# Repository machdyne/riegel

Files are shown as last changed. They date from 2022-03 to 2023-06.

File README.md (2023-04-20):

# Riegel Computer

Riegel is an FPGA computer designed by Lone Dynamics Corporation.

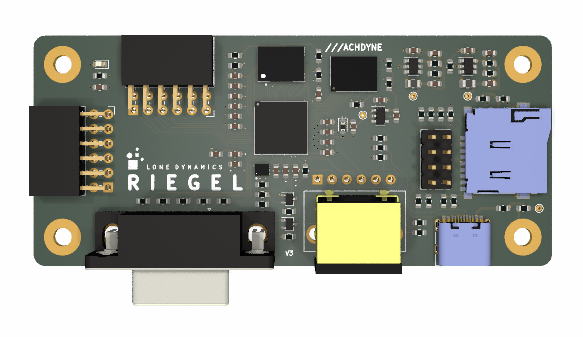
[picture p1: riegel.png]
Riegel Computer


This repo contains schematics, PCB layouts, pinouts, a 3D-printable case, example gateware and documentation.

Find more information on the [Riegel product page](https://machdyne.com/product/riegel-computer/).

## Blinky 

Building the blinky example requires [Yosys](https://github.com/YosysHQ/yosys), [nextpnr-ice40](https://github.com/YosysHQ/nextpnr) and [IceStorm](https://github.com/YosysHQ/icestorm).

Assuming they are installed, you can simply type `make` to build the gateware, which will be written to output/blinky.bin. You can then use [ldprog](https://github.com/machdyne/ldprog) to write the gateware to the device.

## Zucker

[Zucker](https://github.com/machdyne/zucker) is a RISC-V SOC designed specifically for Riegel hardware.

## USB Bootloader

Riegel supports updating the flash MMOD over its USB-C port with the USB DFU (Device Firmware Upgrade) protocol. When Riegel powers on (or restarts) the USB bootloader waits 5 seconds for a USB command and then continues the boot process, if it receives a command it will wait until the device is detached (with `dfu-util -e`) or rebooted (with `ldprog -r`).

In order to install the USB bootloader you will need to use the ISP header and [ldprog](https://github.com/machdyne/ldprog). Make sure you have first installed the software required to build the Blinky example above.

```
git clone https://github.com/machdyne/tinydfu-bootloader
cd tinydfu-bootloader/boards/riegel
make
make prog
```

Now you can program the flash MMOD over USB:

```
ldprog -r
sudo dfu-util -a 0 -D zucker/output/soc.bin
sudo dfu-util -a 1 -D zucker/apps/lix/lix.bin
```

Note: It may be necessary to remove the MicroSD card before programming with DFU.

Exit the bootloader and continue booting:

```
sudo dfu-util -e -a 0
```

## ISP Header

The ISP header can be used to program the FPGA SRAM as well as the MMOD flash memory. 

```
1 2
3 4
5 6
7 8
```

| Pin | Signal |
| --- | --- |
| 1 | CSPI\_SS |
| 2 | CSPI\_SCK |
| 3 | CSPI\_SI |
| 4 | CSPI\_SO |
| 5 | CRESET |
| 6 | CDONE |
| 7 | GND |
| 8 | PWR3V3 (out) |

## Board Revisions

| Revision | Notes |
| --- | ----- |
| V3B | Latest production board |
| V4 | Work in progress; improves USB routing  |

## License

The contents of this repo are released under the [Lone Dynamics Open License](LICENSE.md) with the following exceptions:

- The KiCad design files contain parts of the [kicad-pmod](https://github.com/mithro/kicad-pmod) library which is released under the [Apache License, Version 2.0](https://www.apache.org/licenses/LICENSE-2.0.html).

- The KiCad design files may contain symbols and footprints released under other licenses; please contact us if we've failed to give proper attribution.

Note: You can use these designs for commercial purposes but we ask that instead of producing exact clones, that you either replace our trademarks and logos with your own or add your own next to ours.

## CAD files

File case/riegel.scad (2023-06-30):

/*
 * Riegel Case
 * Copyright (c) 2022 Lone Dynamics Corporation. All rights reserved.
 *
 */

$fn = 100;

dev_edition = true;

board_width = 40;
board_thickness = 1.5;
board_length = 90;
board_height = 20;
board_spacing = 2;

ldq_board();

translate([0,0,15])
	ldq_case_top();

translate([0,0,-15])
	ldq_case_bottom();

module ldq_board() {
	
	difference() {
		color([0,0.5,0])
			roundedcube(board_width,board_length,board_thickness,2);
		translate([5, 5, -1]) cylinder(d=3.2, h=10);
		translate([5, 85, -1]) cylinder(d=3.2, h=10);
		translate([35, 5, -1]) cylinder(d=3.2, h=10);
		translate([35, 85, -1]) cylinder(d=3.2, h=10);
	}	
	
}

module ldq_case_top() {
	
	difference() {
				
		color([0.5,0.5,0.5])
			roundedcube(board_width,board_length,15,2);
			
		translate([1.5,2,-2])
			roundedcube(board_width-3.5,board_length-4,4,2);

		translate([1.5,10,-2])
			roundedcube(board_width-8,board_length-20,15,2);

		translate([10,2,-2])
			roundedcube(board_width-20,board_length-4,15,2);
		
		if (dev_edition) {
			// ISP header
			translate([16,66.5,2]) cube([12,6,20]);
		}
		
		// VGA
		translate([30,26.2-(31/2),-2]) cube([30,31,12.5+2]);

		// PS2
		translate([30,55.6-(14.5/2),-2]) cube([30,14.5,13+2]);

		// USBC
		translate([30,74.45-(9.5/2),-2]) cube([30,9.5,3.5+1.75]);
		
		// SD
		translate([20-(15/2),70,-2]) cube([15,30,2+2]);

		// SD resistor cutouts
		translate([8,74,-2]) cube([15,10,2+2]);
		translate([17,74,-2]) cube([15,10,2+2]);

		// PMODA
		translate([20,-2,0]) cube([16,30,10],center=true);

		// PMODB
		translate([0,23.65,0]) cube([5,16,10], center=true);
		
		// bolt holes
		translate([5, 5, -21]) cylinder(d=3.5, h=40);
		translate([5, 85, -21]) cylinder(d=3.5, h=40);
		translate([35, 5, -20]) cylinder(d=3.5, h=40);
		translate([35, 85, -21]) cylinder(d=3.5, h=40);

		// flush mount bolt holes
		translate([5, 5, 14]) cylinder(d=5, h=4);
		translate([5, 85, 14]) cylinder(d=5, h=4);
		translate([35, 5, 14]) cylinder(d=5, h=4);
		translate([35, 85, 14]) cylinder(d=5, h=4);

		// riegel text
		rotate(270)
			translate([-35,18.5,14])
				linear_extrude(5)
					text("R I E G E L", size=6, halign="center",
						font="Ubuntu:style=Bold");

	}	
}

module ldq_case_bottom() {
	
	difference() {
		color([0.5,0.5,0.5])
			roundedcube(board_width,board_length,8.5,2);
		
		translate([2,10,2])
			roundedcube(board_width-4,board_length-20,8,2);
				
		translate([10,2.5,2])
			roundedcube(board_width-20,board_length-5,8,2);

		// bolt holes
		translate([5, 5, -11]) cylinder(d=3.2, h=25);
		translate([5, 85, -11]) cylinder(d=3.2, h=25);
		translate([35, 5, -11]) cylinder(d=3.2, h=25);
		translate([35, 85, -11]) cylinder(d=3.2, h=25);

		// nut holes
		translate([5, 5, -1.5]) cylinder(d=7, h=4.5, $fn=6);
		translate([5, 85, -1.5]) cylinder(d=7, h=4.5, $fn=6);
		translate([35, 5, -1.5]) cylinder(d=7, h=4.5, $fn=6);
		translate([35, 85, -1.5]) cylinder(d=7, h=4.5, $fn=6);

	}	
}

// https://gist.github.com/tinkerology/ae257c5340a33ee2f149ff3ae97d9826
module roundedcube(xx, yy, height, radius)
{
    translate([0,0,height/2])
    hull()
    {
        translate([radius,radius,0])
        cylinder(height,radius,radius,true);

        translate([xx-radius,radius,0])
        cylinder(height,radius,radius,true);

        translate([xx-radius,yy-radius,0])
        cylinder(height,radius,radius,true);

        translate([radius,yy-radius,0])
        cylinder(height,radius,radius,true);
    }
}

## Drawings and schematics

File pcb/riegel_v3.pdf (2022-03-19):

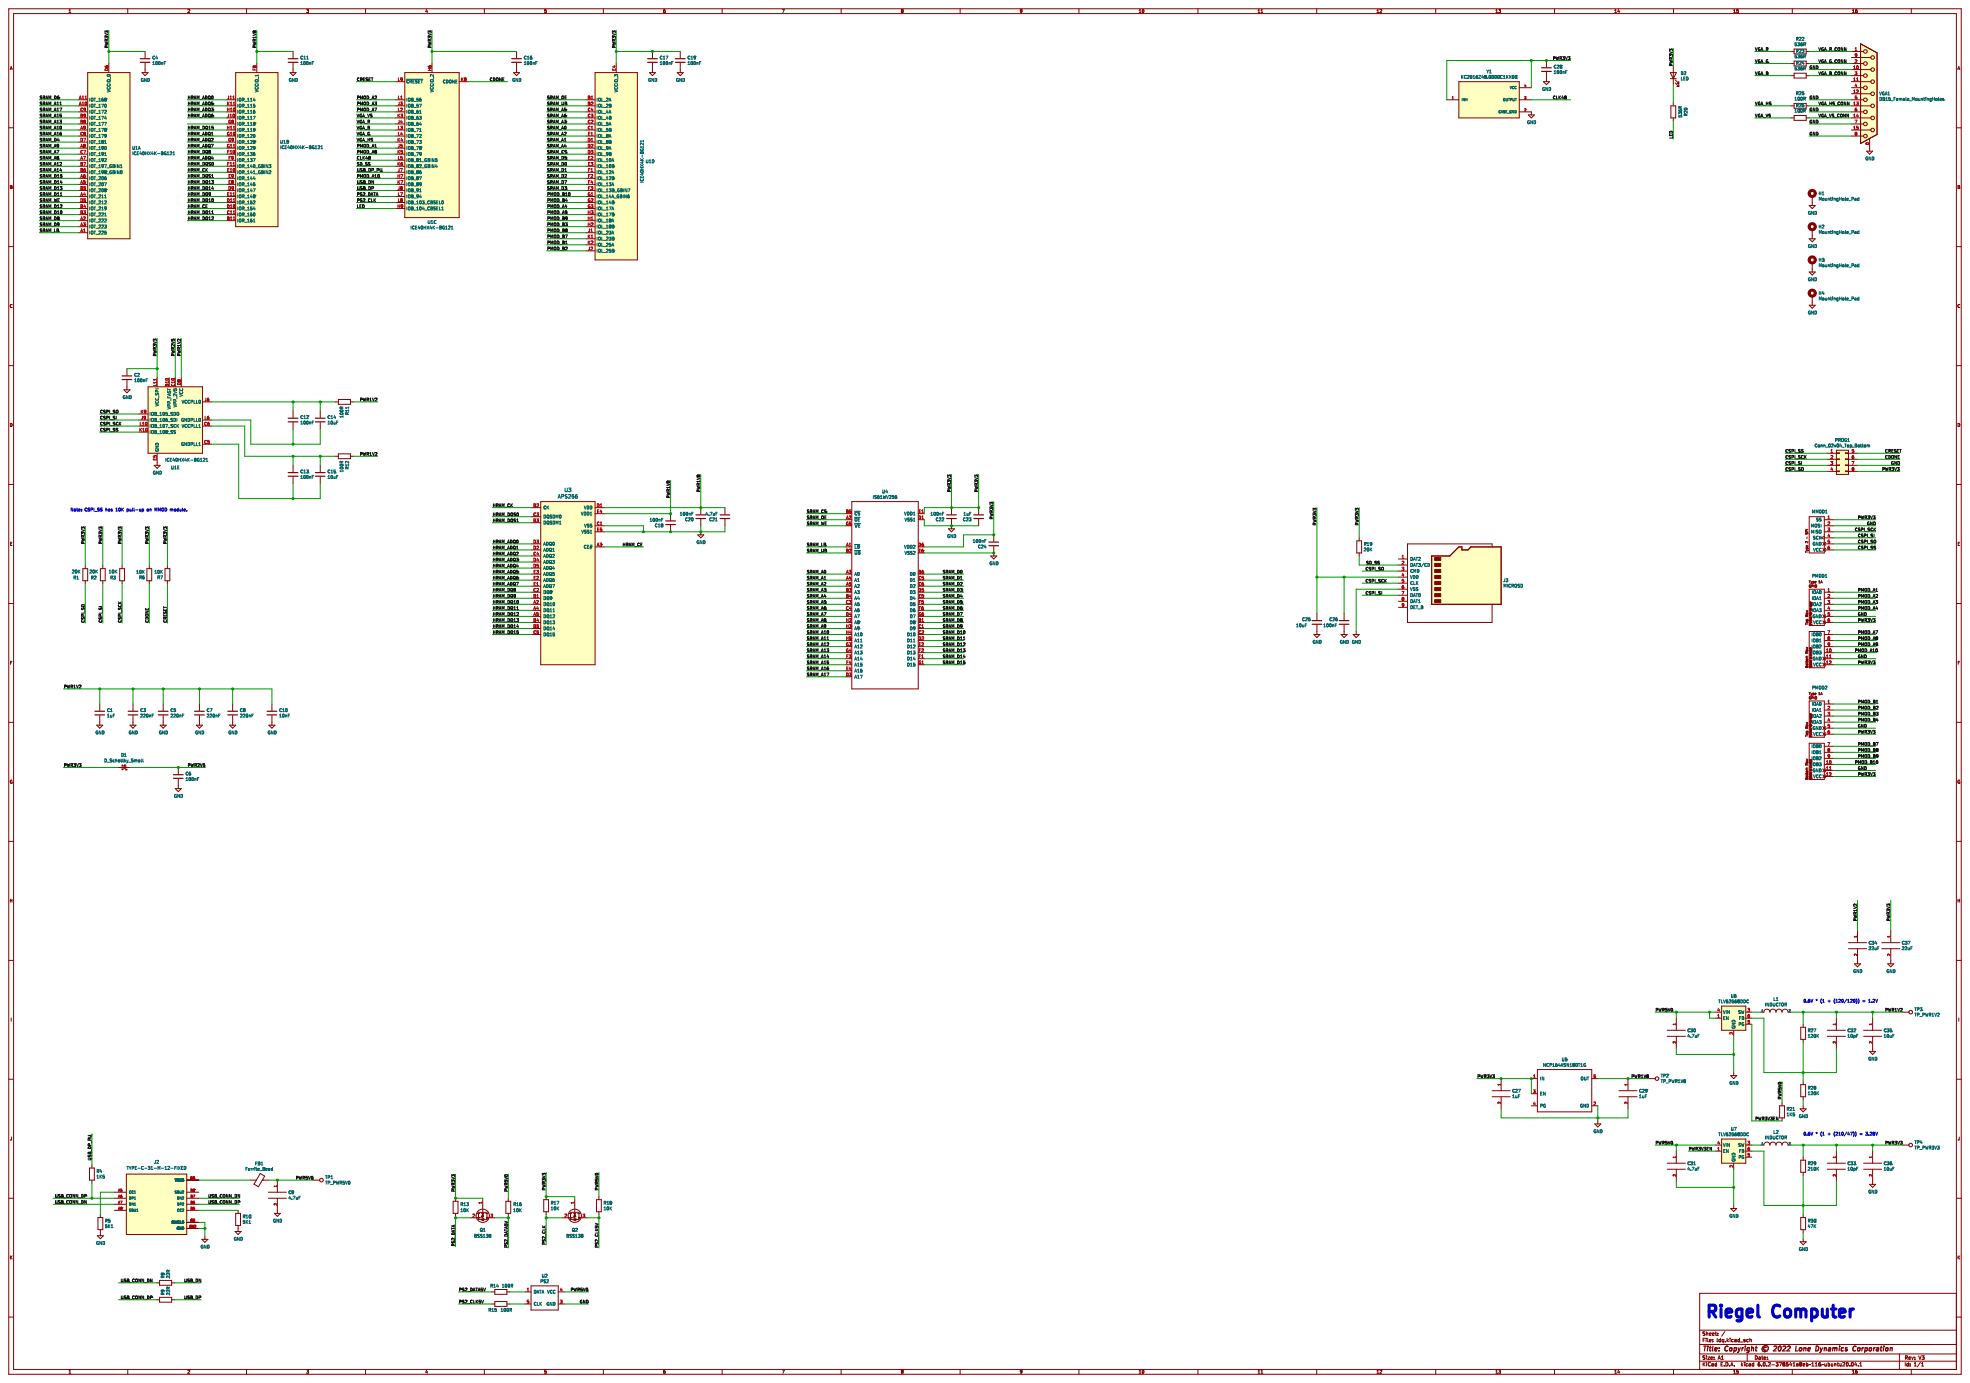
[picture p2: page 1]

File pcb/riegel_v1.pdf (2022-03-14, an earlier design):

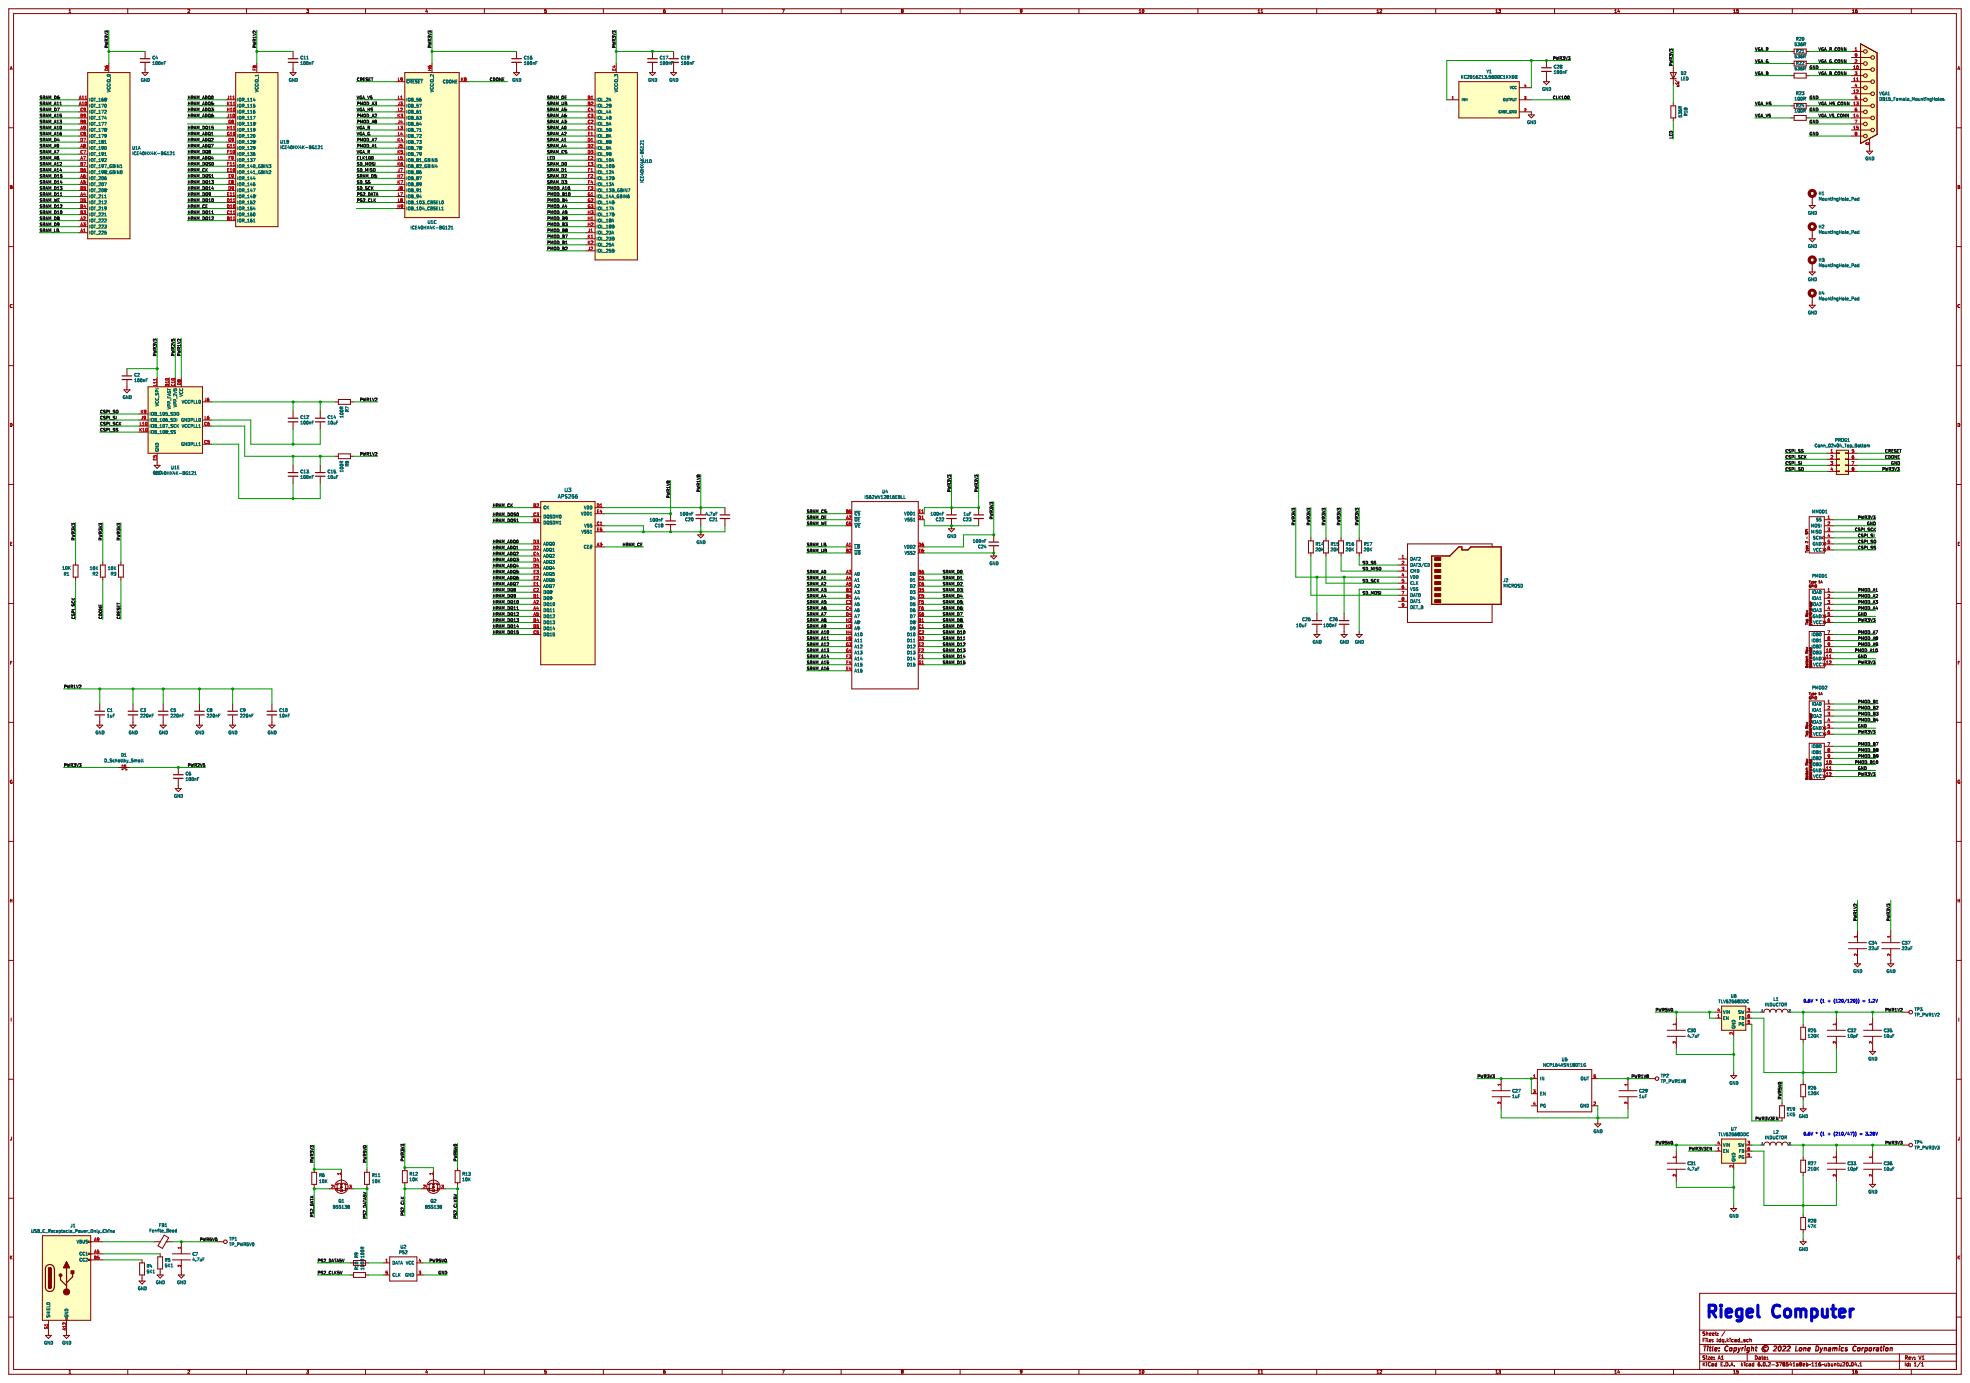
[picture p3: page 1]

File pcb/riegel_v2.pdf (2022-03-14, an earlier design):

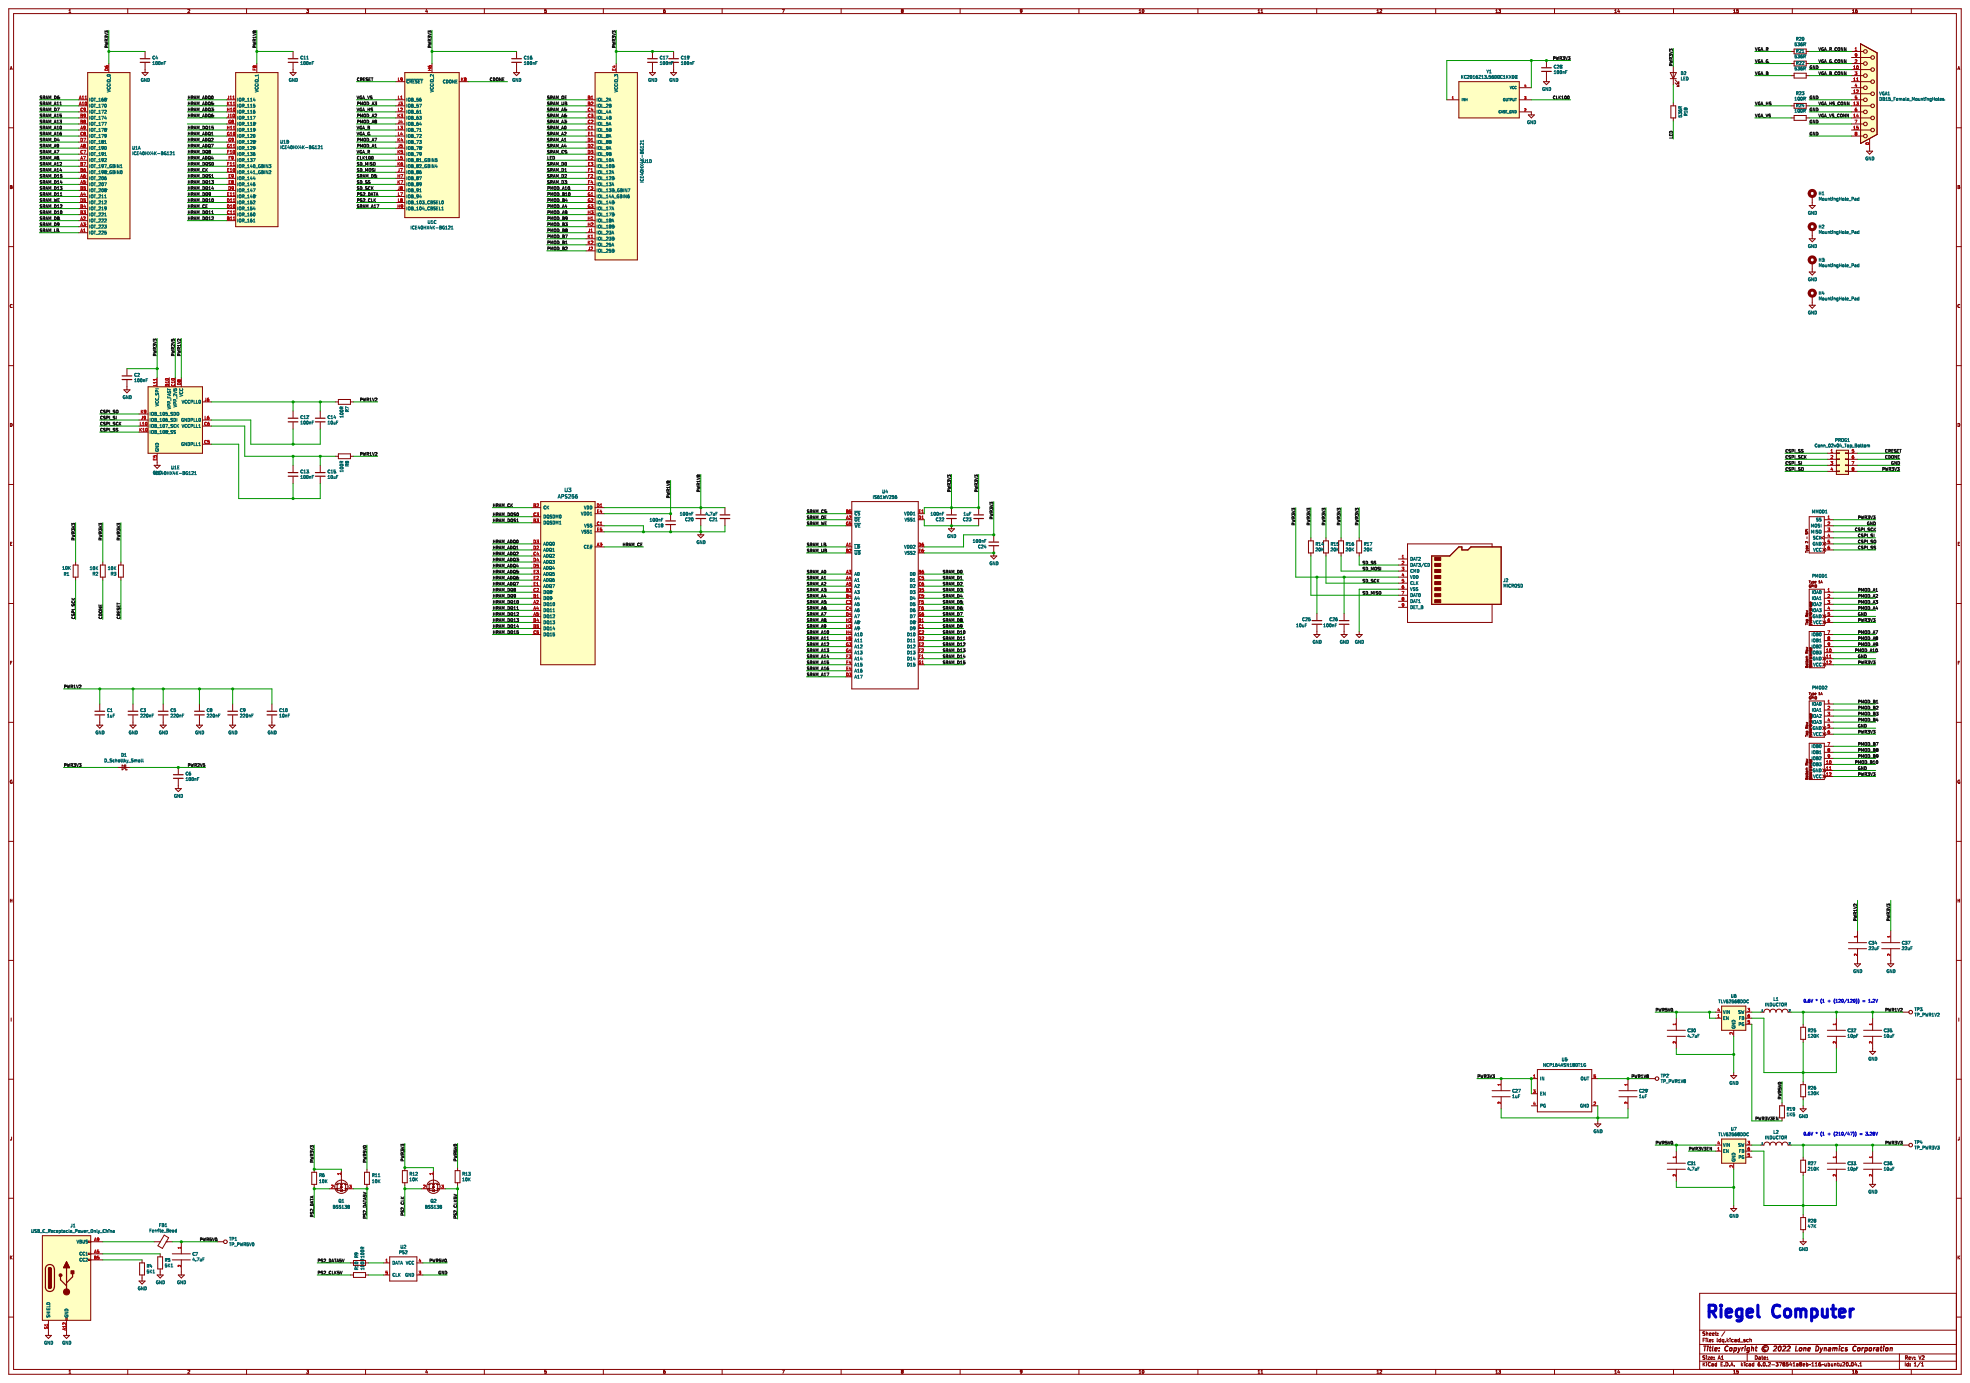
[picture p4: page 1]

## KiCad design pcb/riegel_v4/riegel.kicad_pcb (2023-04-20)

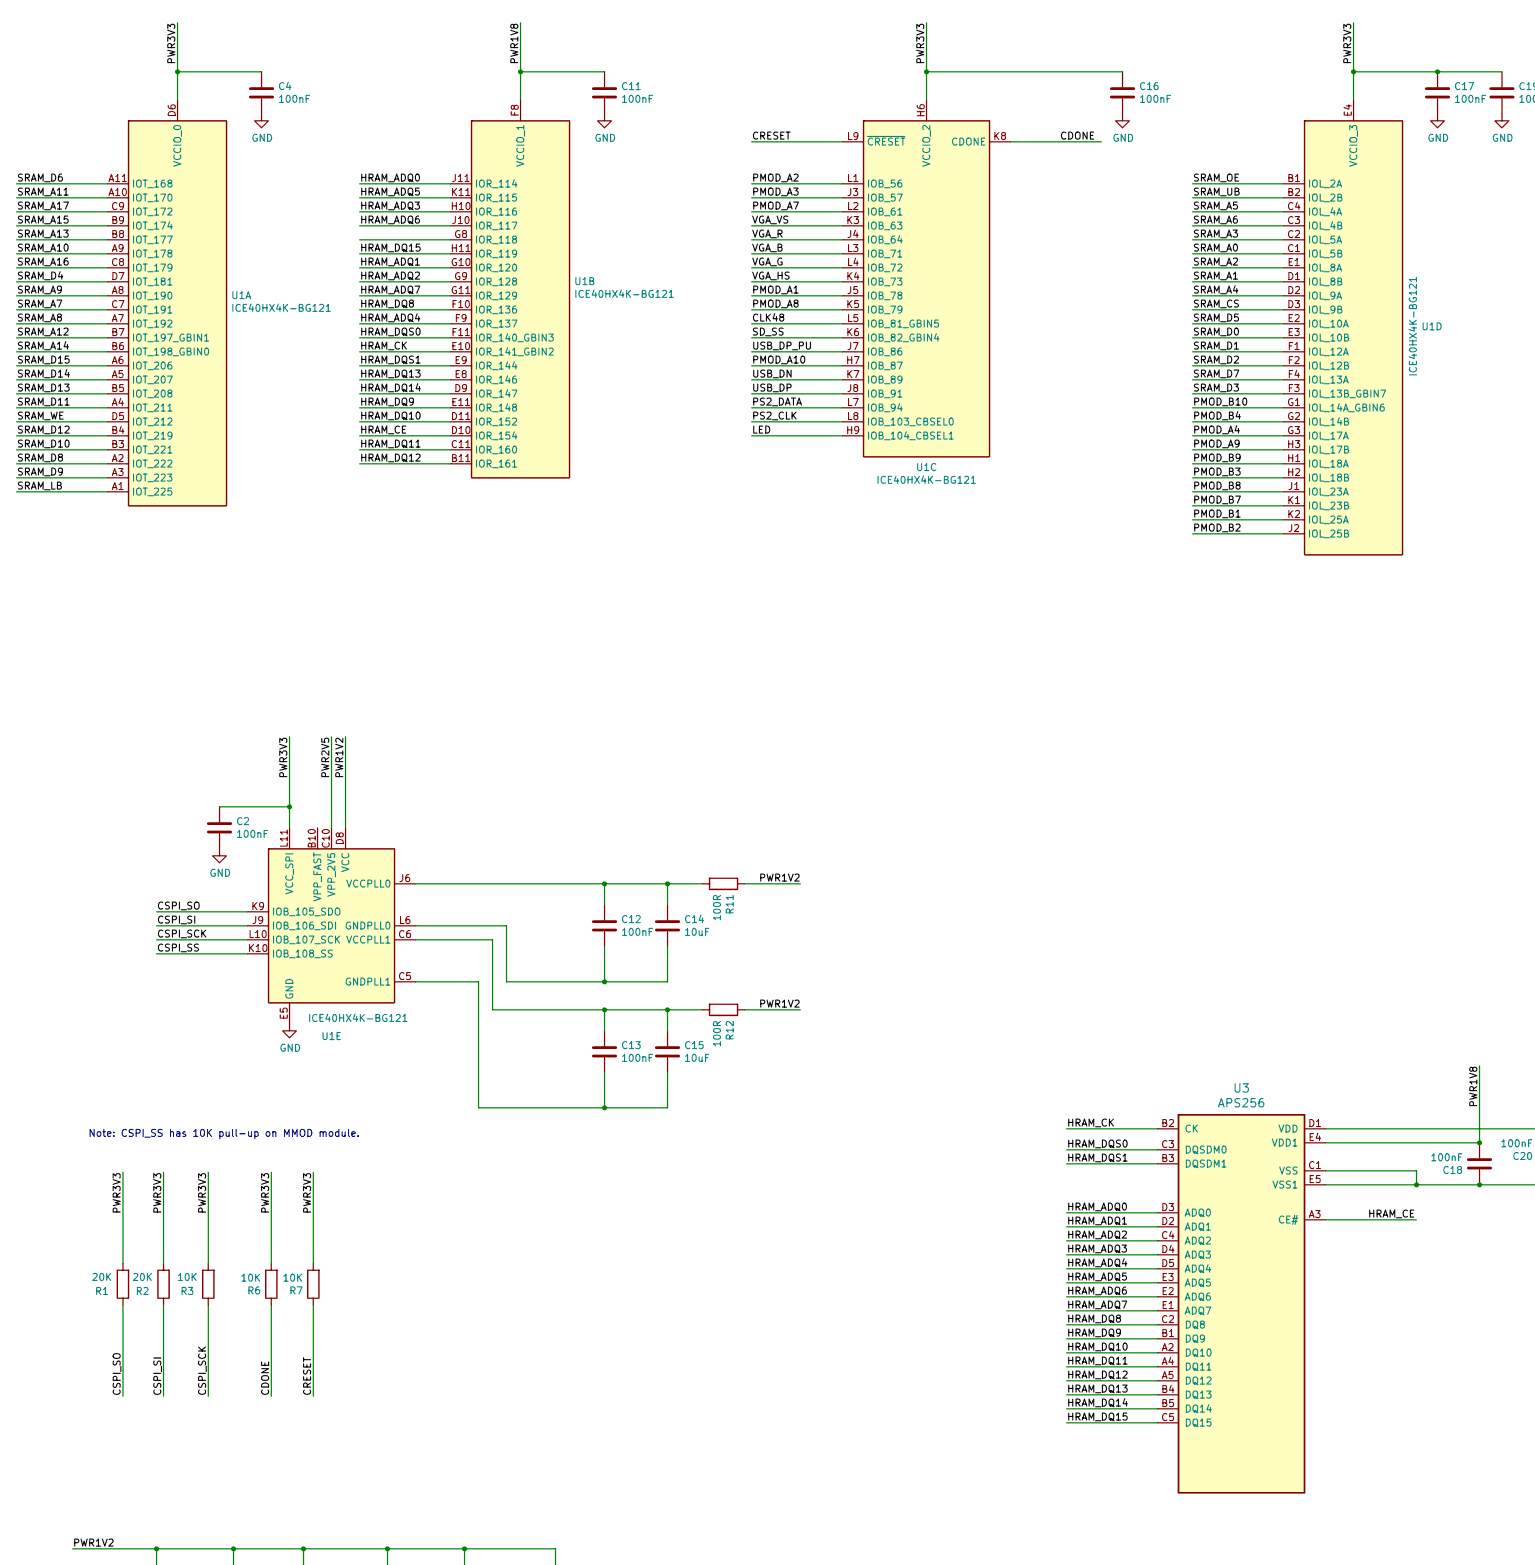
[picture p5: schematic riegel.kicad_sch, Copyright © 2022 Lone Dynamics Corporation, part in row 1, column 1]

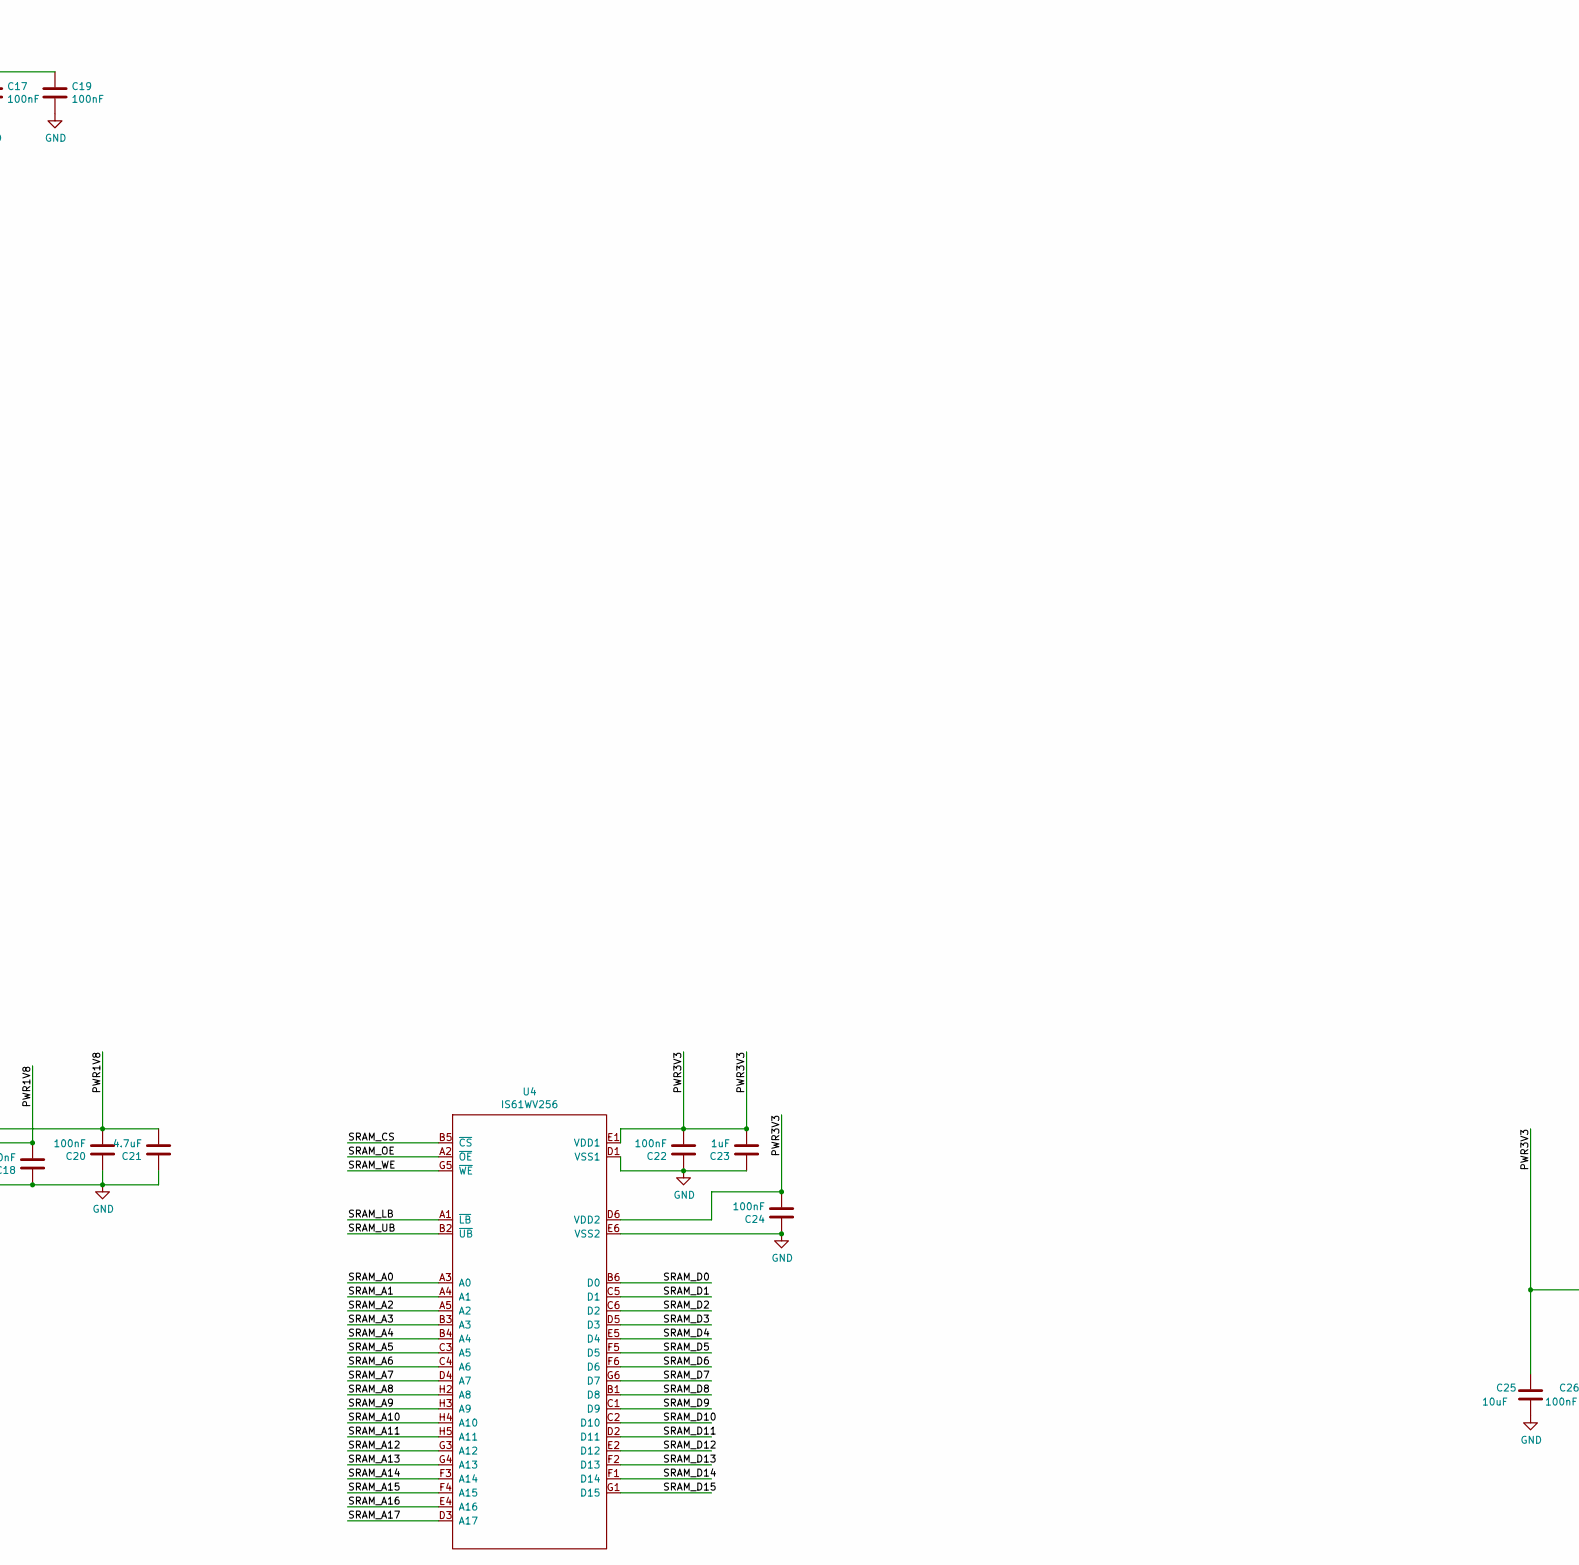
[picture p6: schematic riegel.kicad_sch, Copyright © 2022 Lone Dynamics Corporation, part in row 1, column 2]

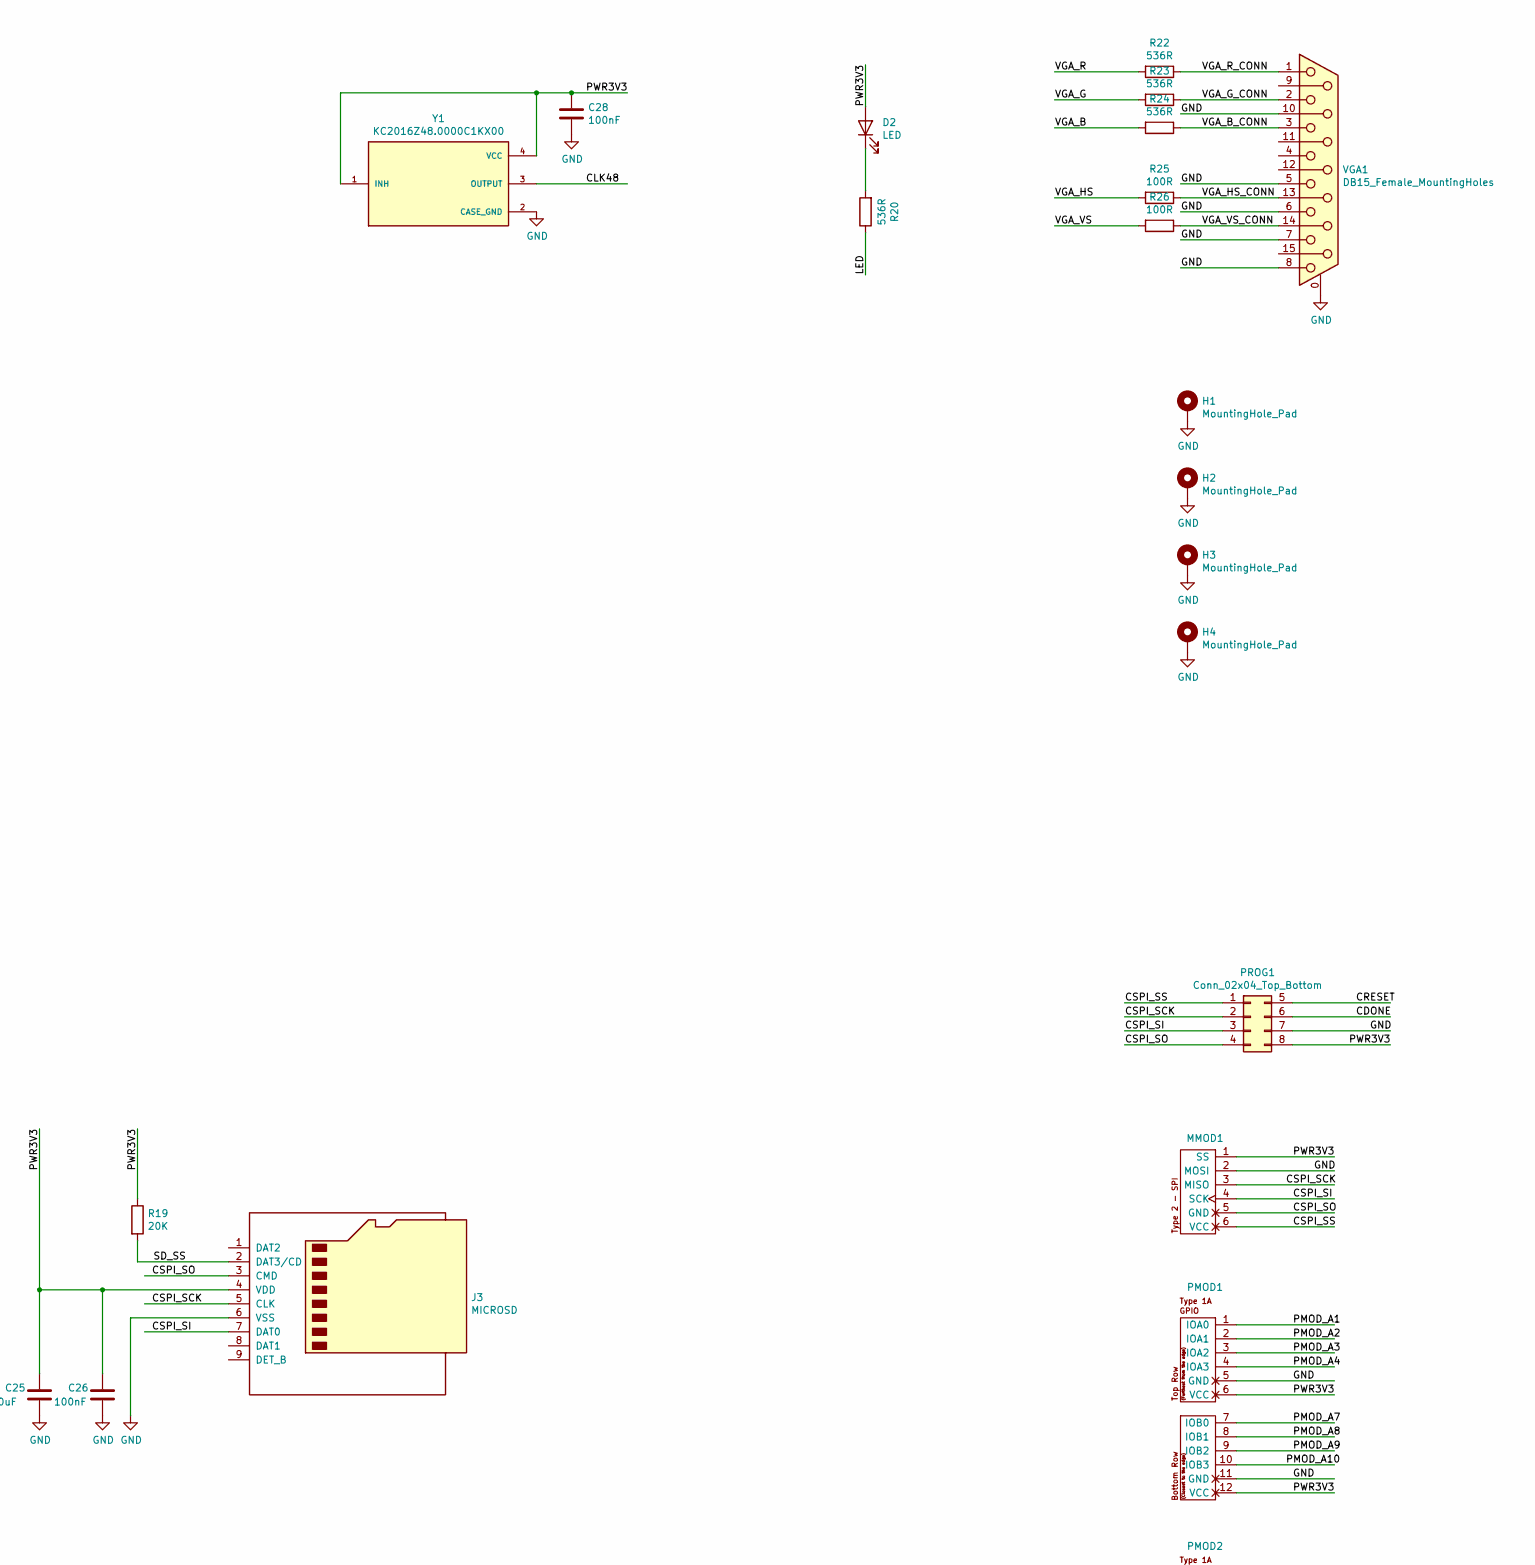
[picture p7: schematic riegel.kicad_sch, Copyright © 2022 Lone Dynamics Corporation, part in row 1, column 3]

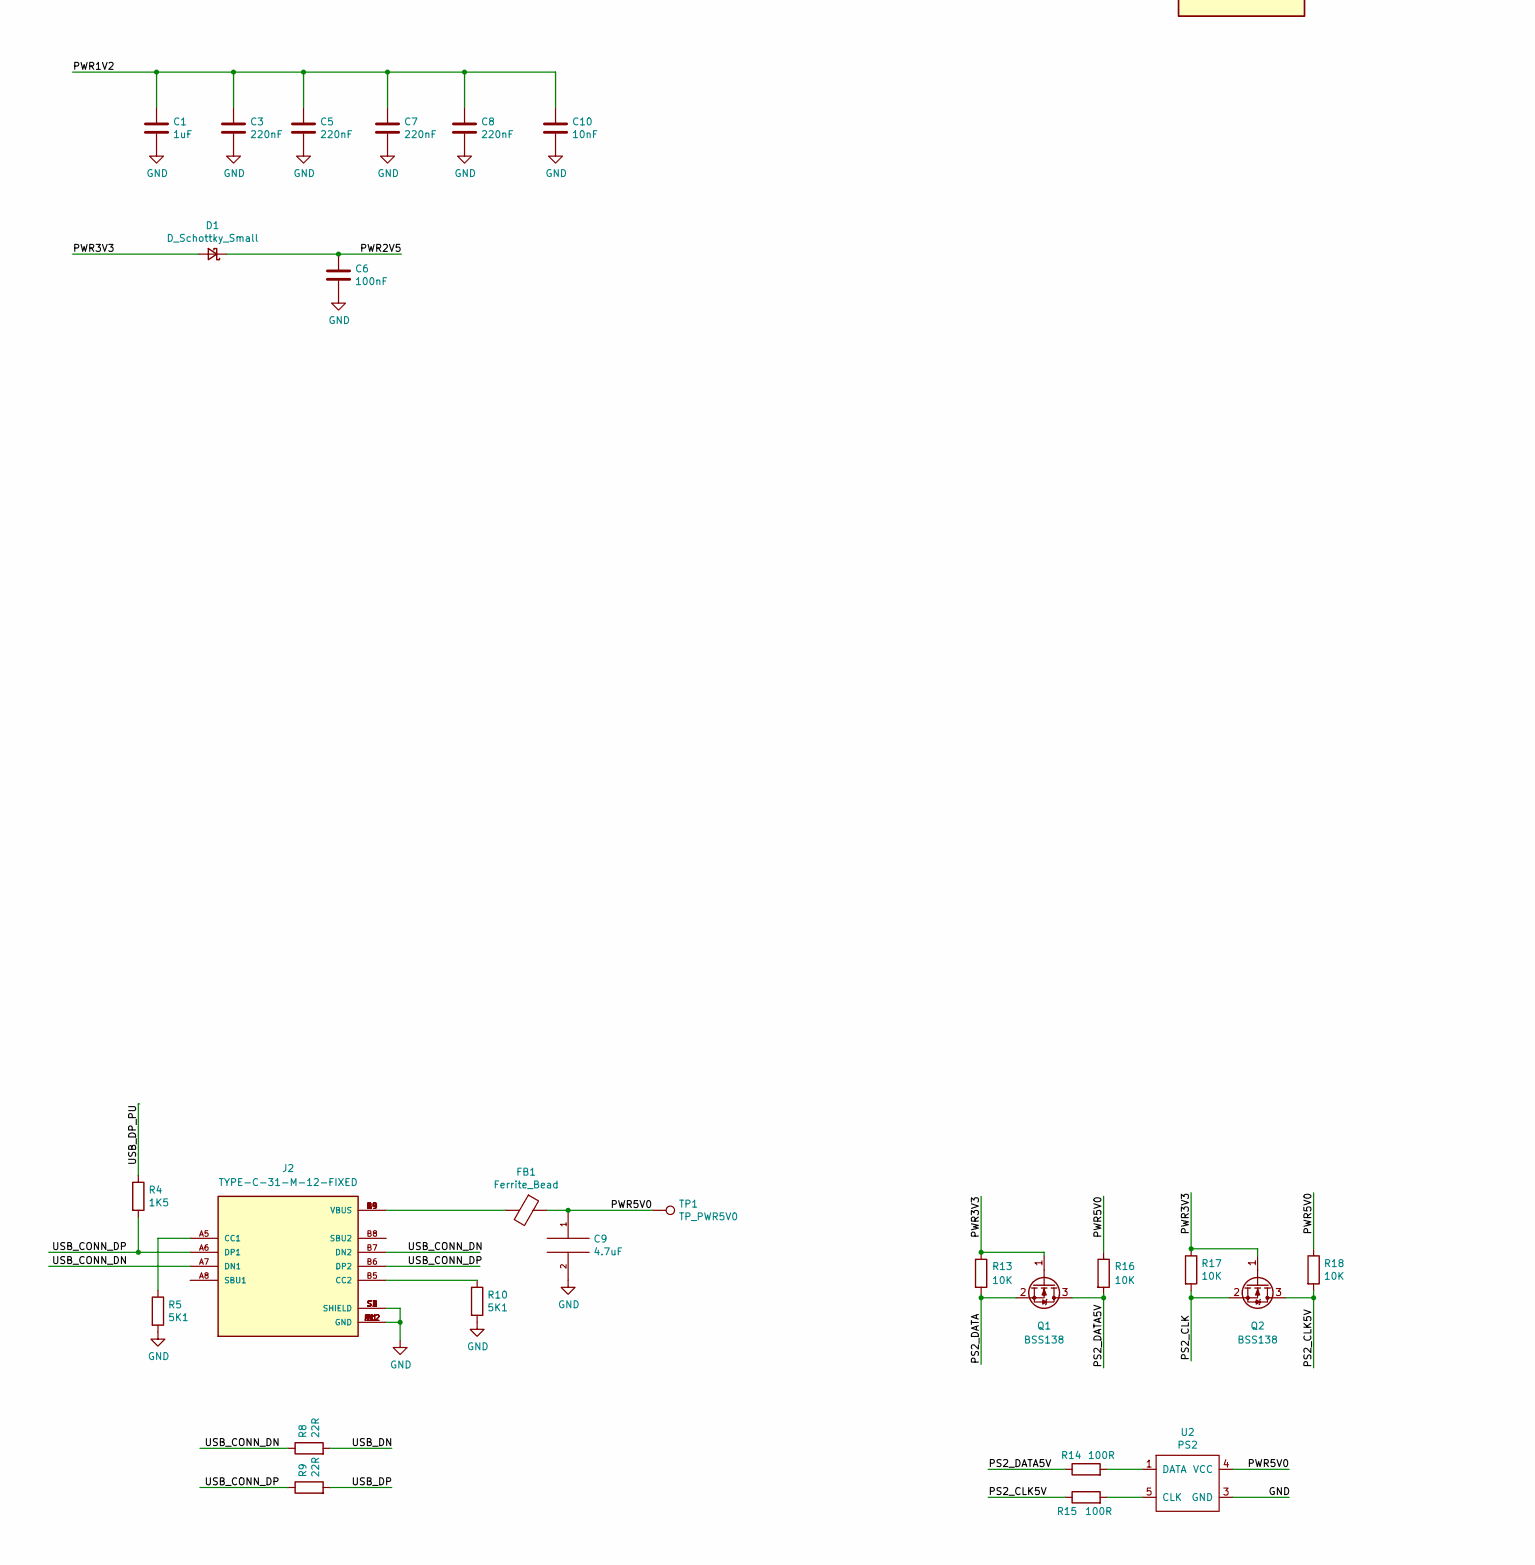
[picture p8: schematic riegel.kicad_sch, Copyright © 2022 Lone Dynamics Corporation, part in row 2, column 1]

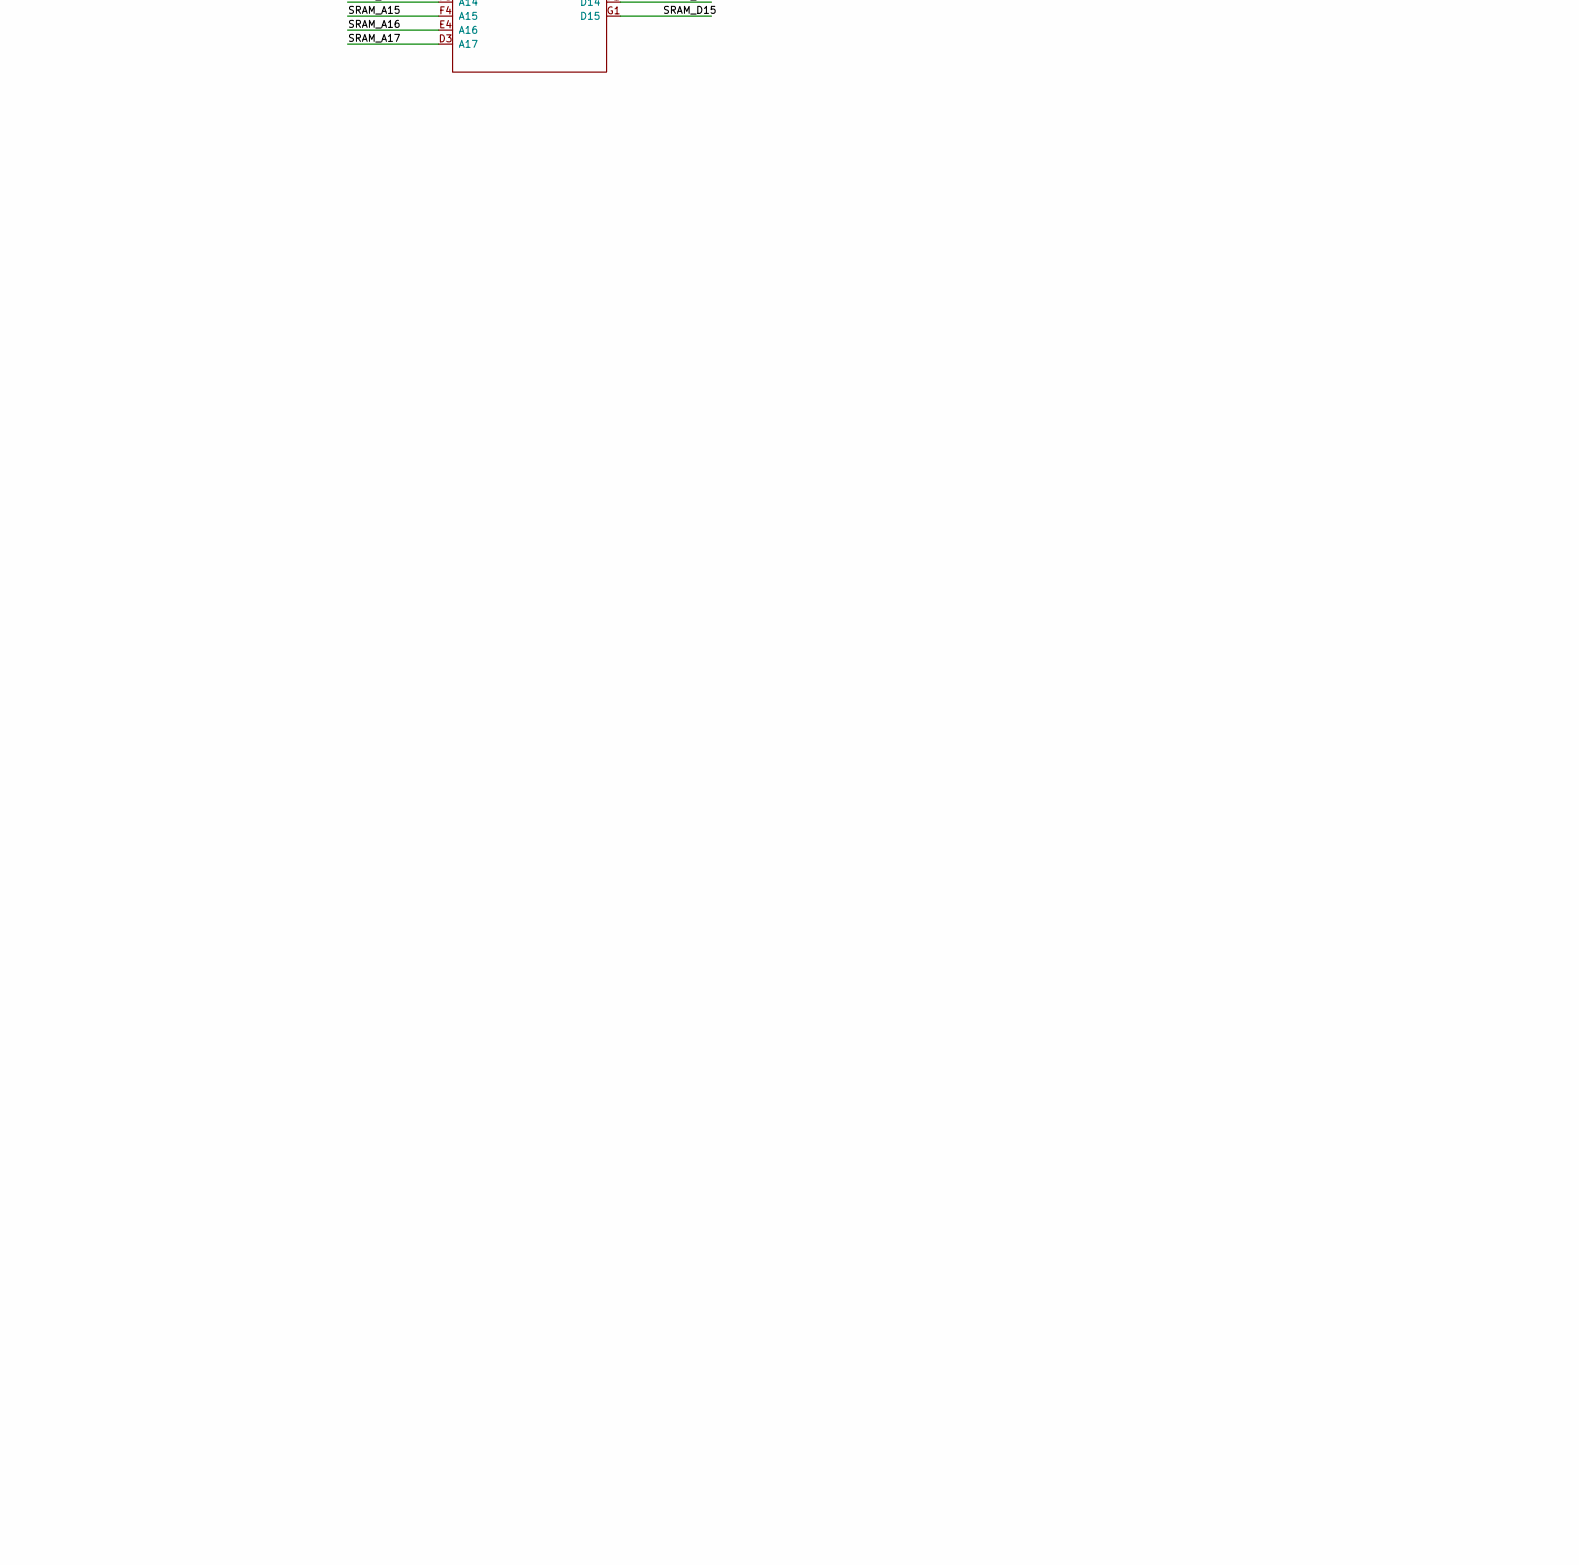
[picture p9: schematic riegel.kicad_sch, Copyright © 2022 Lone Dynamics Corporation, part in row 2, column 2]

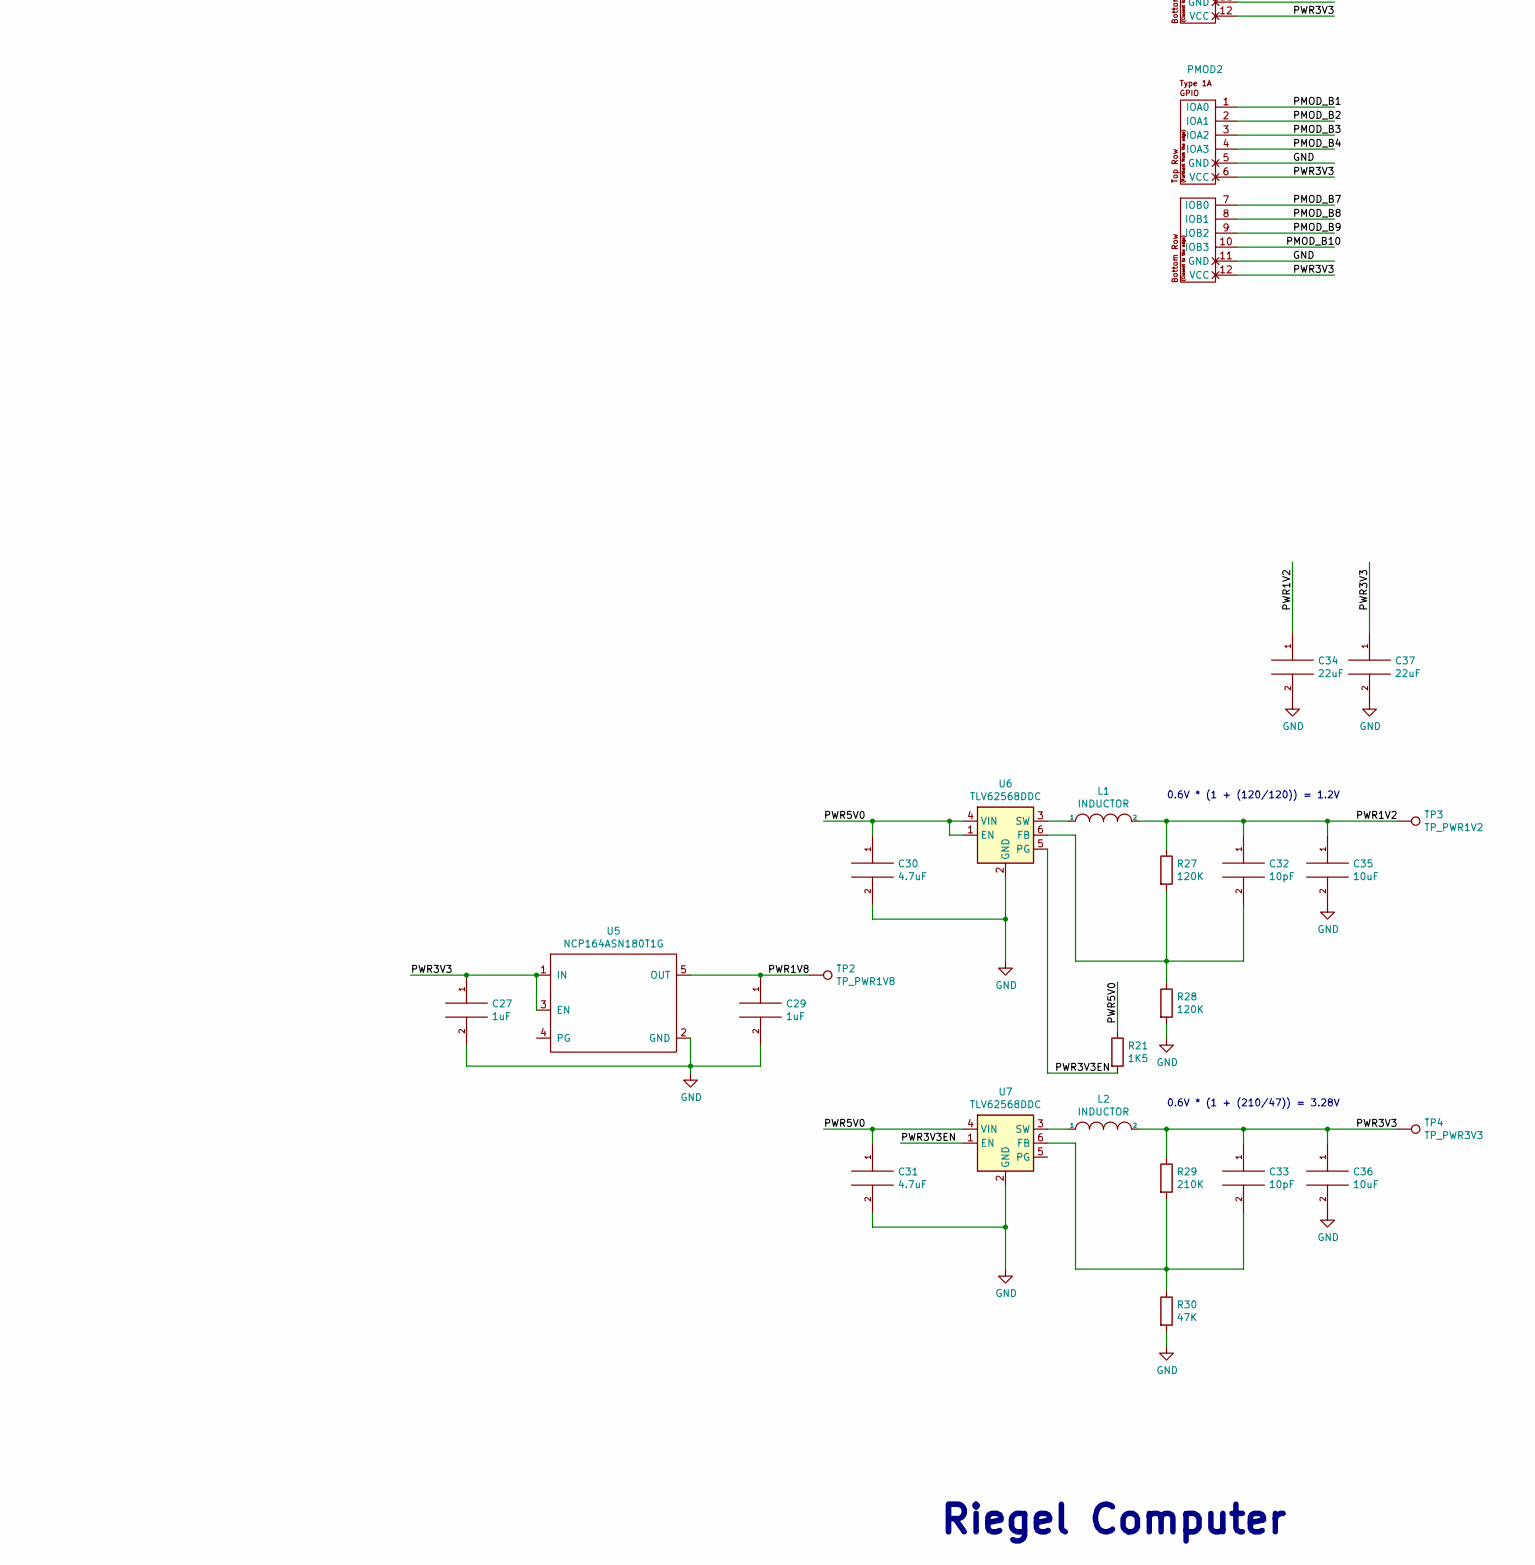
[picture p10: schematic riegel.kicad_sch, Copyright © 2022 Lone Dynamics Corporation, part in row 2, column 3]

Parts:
C1, C27, C29: 1uF; C_0603_1608Metric
C2, C4, C6, C11, C12, C13, C16, C17, C19: 100nF; C_0603_1608Metric
C3, C5, C7, C8: 220nF; C_0603_1608Metric
C9, C21: 4.7uF; R_0603_1608Metric
C10: 10nF; C_0603_1608Metric
C14, C15, C35, C36: 10uF; C_0603_1608Metric
C18, C20, C22, C24, C26, C28: 100nF; R_0603_1608Metric
C23: 1uF; R_0603_1608Metric
C25: 10uF; R_0603_1608Metric
C30, C31: 4.7uF; C_0603_1608Metric
C32, C33: 10pF; C_0603_1608Metric
C34, C37: 22uF; C_0603_1608Metric
D1: D_Schottky_Small; D_0603_1608Metric
D2: LED; LED_0603_1608Metric
FB1: Ferrite_Bead; R_0603_1608Metric
H1, H2, H3, H4: MountingHole_Pad; MountingHole_3.2mm_M3_Pad
J2: TYPE-C-31-M-12-FIXED; USB_C_Receptacle_HRO_TYPE-C-31-M-12; PARTREV A
J3: MICROSD; SDCARD
L1, L2: INDUCTOR; L_0805_2012Metric
MMOD1: PMOD-Device-x1-Type-2-SPI; PinSocket_1x06_P2.54mm_Horizontal
PMOD1, PMOD2: PMOD-Device-x2-Type-1A-GPIO; PMOD_2x06_HOST
PROG1: Conn_02x04_Top_Bottom; PinHeader_2x04_P2.54mm_Vertical
Q1, Q2: BSS138; SOT-323_SC-70
R1, R2, R19: 20K; R_0603_1608Metric
R3, R6, R7, R13, R16, R17, R18: 10K; R_0603_1608Metric
R4, R21: 1K5; R_0603_1608Metric
R5, R10: 5K1; R_0603_1608Metric
R8, R9: 22R; R_0603_1608Metric
R11, R12, R14, R15, R25, R26: 100R; R_0603_1608Metric
R20, R22, R23, R24: 536R; R_0603_1608Metric
R27, R28: 120K; R_0603_1608Metric
R29: 210K; R_0603_1608Metric
R30: 47K; R_0603_1608Metric
TP1: TP_PWR5V0; TestPoint_THTPad_D1.0mm_Drill0.5mm
TP2: TP_PWR1V8; TestPoint_THTPad_D1.0mm_Drill0.5mm
TP3: TP_PWR1V2; TestPoint_THTPad_D1.0mm_Drill0.5mm
TP4: TP_PWR3V3; TestPoint_THTPad_D1.0mm_Drill0.5mm
U1: ICE40HX4K-BG121; BGA-121_9.0x9.0mm_Layout11x11_P0.8mm_Ball0.4mm_Pad0.35mm_NS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
U2: PS2; MINI-DIN-6-FULL-SHIELD
U3: APS256; APS256_BGA_24
U4: IS61WV256; BGA48C75P8X6_800X600X120N
U5: NCP164ASN180T1G; TSOP-5_1.65x3.05mm_P0.95mm
U6, U7: TLV62568DDC; SOT-23-6
VGA1: DB15_Female_MountingHoles; DSUB-15-HD_Female_Horizontal_P2.29x1.98mm_EdgePinOffset3.03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
Y1: KC2016Z48.0000C1KX00; OSC_KC2016Z13.5600C1KX00; PARTREV November 2020

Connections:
/CDONE: PROG1.6, R6.1, U1.K8 (CDONE)
/CLK48: U1.L5 (IOB_81_GBIN5), Y1.3 (OUTPUT)
/CRESET: PROG1.5, R7.1, U1.L9 (~CRESET)
/CSPI_SCK: J3.5 (CLK), MMOD1.3 (MISO), PROG1.2, R3.1, U1.L10 (IOB_107_SCK)
/CSPI_SI: J3.7 (DAT0), MMOD1.4 (SCK), PROG1.3, R2.1, U1.J9 (IOB_106_SDI)
/CSPI_SO: J3.3 (CMD), MMOD1.5 (GND), PROG1.4, R1.1, U1.K9 (IOB_105_SDO)
/CSPI_SS: MMOD1.6 (VCC), PROG1.1, U1.K10 (IOB_108_SS)
/HRAM_ADQ0: U1.J11 (IOR_114), U3.D3 (ADQ0)
/HRAM_ADQ1: U1.G10 (IOR_120), U3.D2 (ADQ1)
/HRAM_ADQ2: U1.G9 (IOR_128), U3.C4 (ADQ2)
/HRAM_ADQ3: U1.H10 (IOR_116), U3.D4 (ADQ3)
/HRAM_ADQ4: U1.F9 (IOR_137), U3.D5 (ADQ4)
/HRAM_ADQ5: U1.K11 (IOR_115), U3.E3 (ADQ5)
/HRAM_ADQ6: U1.J10 (IOR_117), U3.E2 (ADQ6)
/HRAM_ADQ7: U1.G11 (IOR_129), U3.E1 (ADQ7)
/HRAM_CE: U1.D10 (IOR_154), U3.A3 (CE#)
/HRAM_CK: U1.E10 (IOR_141_GBIN2), U3.B2 (CK)
/HRAM_DQ8: U1.F10 (IOR_136), U3.C2 (DQ8)
/HRAM_DQ9: U1.E11 (IOR_148), U3.B1 (DQ9)
/HRAM_DQ10: U1.D11 (IOR_152), U3.A2 (DQ10)
/HRAM_DQ11: U1.C11 (IOR_160), U3.A4 (DQ11)
/HRAM_DQ12: U1.B11 (IOR_161), U3.A5 (DQ12)
/HRAM_DQ13: U1.E8 (IOR_146), U3.B4 (DQ13)
/HRAM_DQ14: U1.D9 (IOR_147), U3.B5 (DQ14)
/HRAM_DQ15: U1.H11 (IOR_119), U3.C5 (DQ15)
/HRAM_DQS0: U1.F11 (IOR_140_GBIN3), U3.C3 (DQSDM0)
/HRAM_DQS1: U1.E9 (IOR_144), U3.B3 (DQSDM1)
/LED: R20.1, U1.H9 (IOB_104_CBSEL1)
/PMOD_A1: PMOD1.1 (IOA0), U1.J5 (IOB_78)
/PMOD_A2: PMOD1.2 (IOA1), U1.L1 (IOB_56)
/PMOD_A3: PMOD1.3 (IOA2), U1.J3 (IOB_57)
/PMOD_A4: PMOD1.4 (IOA3), U1.G3 (IOL_17A)
/PMOD_A7: PMOD1.7 (IOB0), U1.L2 (IOB_61)
/PMOD_A8: PMOD1.8 (IOB1), U1.K5 (IOB_79)
/PMOD_A9: PMOD1.9 (IOB2), U1.H3 (IOL_17B)
/PMOD_A10: PMOD1.10 (IOB3), U1.H7 (IOB_87)
/PMOD_B1: PMOD2.1 (IOA0), U1.K2 (IOL_25A)
/PMOD_B2: PMOD2.2 (IOA1), U1.J2 (IOL_25B)
/PMOD_B3: PMOD2.3 (IOA2), U1.H2 (IOL_18B)
/PMOD_B4: PMOD2.4 (IOA3), U1.G2 (IOL_14B)
/PMOD_B7: PMOD2.7 (IOB0), U1.K1 (IOL_23B)
/PMOD_B8: PMOD2.8 (IOB1), U1.J1 (IOL_23A)
/PMOD_B9: PMOD2.9 (IOB2), U1.H1 (IOL_18A)
/PMOD_B10: PMOD2.10 (IOB3), U1.G1 (IOL_14A_GBIN6)
/PS2_CLK: Q2.2 (S), R17.2, U1.L8 (IOB_103_CBSEL0)
/PS2_CLK5V: Q2.3 (D), R15.1, R18.2
/PS2_DATA: Q1.2 (S), R13.2, U1.L7 (IOB_94)
/PS2_DATA5V: Q1.3 (D), R14.1, R16.2
/PWR1V2: C1.1, C3.1, C5.1, C7.1, C8.1, C10.1, C32.1, C34.1, C35.1, L1.2, R11.1, R12.1, R27.1, TP3.1, U1.D4 (VCC), U1.D8 (VCC), U1.H4 (VCC), U1.H8 (VCC)
/PWR1V8: C11.1, C18.2, C20.2, C21.2, C29.1, TP2.1, U1.F8 (VCCIO_1), U3.D1 (VDD), U3.E4 (VDD1), U5.5 (OUT)
/PWR2V5: C6.1, D1.1 (K), U1.C10 (VPP_2V5)
/PWR3V3: C2.1, C4.1, C16.1, C17.1, C19.1, C22.2, C23.2, C24.2, C25.1, C26.1, C27.1, C28.1, C33.1, C36.1, C37.1, D1.2 (A), D2.2 (A), J3.4 (VDD), L2.2, MMOD1.1 (SS), PMOD1.6 (VCC), PMOD1.12 (VCC), PMOD2.6 (VCC), PMOD2.12 (VCC), PROG1.8, Q1.1 (G), Q2.1 (G), R1.2, R2.2, R3.2, R6.2, R7.2, R13.1, R17.1, R19.1, R29.1, TP4.1, U1.D6 (VCCIO_0), U1.E4 (VCCIO_3), U1.G4 (VCCIO_3), U1.H6 (VCCIO_2), U1.L11 (VCC_SPI), U4.D6 (VDD2), U4.E1 (VDD1), U5.1 (IN), U5.3 (EN), Y1.1 (INH), Y1.4 (VCC)
/PWR3V3EN: R21.2, U6.5 (PG), U7.1 (EN)
/PWR5V0: C9.1, C30.1, C31.1, FB1.1, R16.1, R18.1, R21.1, TP1.1, U2.4 (VCC), U6.1 (EN), U6.4 (VIN), U7.4 (VIN)
/SD_SS: J3.2 (DAT3/CD), R19.2, U1.K6 (IOB_82_GBIN4)
/SRAM_A0: U1.C1 (IOL_5B), U4.A3 (A0)
/SRAM_A1: U1.D1 (IOL_8B), U4.A4 (A1)
/SRAM_A2: U1.E1 (IOL_8A), U4.A5 (A2)
/SRAM_A3: U1.C2 (IOL_5A), U4.B3 (A3)
/SRAM_A4: U1.D2 (IOL_9A), U4.B4 (A4)
/SRAM_A5: U1.C4 (IOL_4A), U4.C3 (A5)
/SRAM_A6: U1.C3 (IOL_4B), U4.C4 (A6)
/SRAM_A7: U1.C7 (IOT_191), U4.D4 (A7)
/SRAM_A8: U1.A7 (IOT_192), U4.H2 (A8)
/SRAM_A9: U1.A8 (IOT_190), U4.H3 (A9)
/SRAM_A10: U1.A9 (IOT_178), U4.H4 (A10)
/SRAM_A11: U1.A10 (IOT_170), U4.H5 (A11)
/SRAM_A12: U1.B7 (IOT_197_GBIN1), U4.G3 (A12)
/SRAM_A13: U1.B8 (IOT_177), U4.G4 (A13)
/SRAM_A14: U1.B6 (IOT_198_GBIN0), U4.F3 (A14)
/SRAM_A15: U1.B9 (IOT_174), U4.F4 (A15)
/SRAM_A16: U1.C8 (IOT_179), U4.E4 (A16)
/SRAM_A17: U1.C9 (IOT_172), U4.D3 (A17)
/SRAM_CS: U1.D3 (IOL_9B), U4.B5 (~CS)
/SRAM_D0: U1.E3 (IOL_10B), U4.B6 (D0)
/SRAM_D1: U1.F1 (IOL_12A), U4.C5 (D1)
/SRAM_D2: U1.F2 (IOL_12B), U4.C6 (D2)
/SRAM_D3: U1.F3 (IOL_13B_GBIN7), U4.D5 (D3)
/SRAM_D4: U1.D7 (IOT_181), U4.E5 (D4)
/SRAM_D5: U1.E2 (IOL_10A), U4.F5 (D5)
/SRAM_D6: U1.A11 (IOT_168), U4.F6 (D6)
/SRAM_D7: U1.F4 (IOL_13A), U4.G6 (D7)
/SRAM_D8: U1.A2 (IOT_222), U4.B1 (D8)
/SRAM_D9: U1.A3 (IOT_223), U4.C1 (D9)
/SRAM_D10: U1.B3 (IOT_221), U4.C2 (D10)
/SRAM_D11: U1.A4 (IOT_211), U4.D2 (D11)
/SRAM_D12: U1.B4 (IOT_219), U4.E2 (D12)
/SRAM_D13: U1.B5 (IOT_208), U4.F2 (D13)
/SRAM_D14: U1.A5 (IOT_207), U4.F1 (D14)
/SRAM_D15: U1.A6 (IOT_206), U4.G1 (D15)
/SRAM_LB: U1.A1 (IOT_225), U4.A1 (~LB)
/SRAM_OE: U1.B1 (IOL_2A), U4.A2 (~OE)
/SRAM_UB: U1.B2 (IOL_2B), U4.B2 (~UB)
/SRAM_WE: U1.D5 (IOT_212), U4.G5 (~WE)
/USB_CONN_DN: J2.A7 (DN1), J2.B7 (DN2), R8.1
/USB_CONN_DP: J2.A6 (DP1), J2.B6 (DP2), R4.2, R9.1
/USB_DN: R8.2, U1.K7 (IOB_89)
/USB_DP: R9.2, U1.J8 (IOB_91)
/USB_DP_PU: R4.1, U1.J7 (IOB_86)
/VGA_B: R24.2, U1.L3 (IOB_71)
/VGA_B_CONN: R24.1, VGA1.3
/VGA_G: R23.2, U1.L4 (IOB_72)
/VGA_G_CONN: R23.1, VGA1.2
/VGA_HS: R25.2, U1.K4 (IOB_73)
/VGA_HS_CONN: R25.1, VGA1.13
/VGA_R: R22.2, U1.J4 (IOB_64)
/VGA_R_CONN: R22.1, VGA1.1
/VGA_VS: R26.2, U1.K3 (IOB_63)
/VGA_VS_CONN: R26.1, VGA1.14
GND: C1.2, C2.2, C3.2, C4.2, C5.2, C6.2, C7.2, C8.2, C9.2, C10.2, C11.2, C16.2, C17.2, C18.1, C19.2, C20.1, C21.1, C22.1, C23.1, C24.1, C25.2, C26.2, C27.2, C28.2, C29.2, C30.2, C31.2, C34.2, C35.2, C36.2, C37.2, H1.1, H2.1, H3.1, H4.1, J2.A1 (GND), J2.A12 (GND), J2.B1 (GND), J2.B12 (GND), J2.S1 (SHIELD), J2.S2 (SHIELD), J2.S3 (SHIELD), J2.S4 (SHIELD), J3.6 (VSS), MMOD1.2 (MOSI), PMOD1.5 (GND), PMOD1.11 (GND), PMOD2.5 (GND), PMOD2.11 (GND), PROG1.7, R5.2, R10.2, R28.2, R30.2, U1.E5 (GND), U1.E6 (GND), U1.E7 (GND), U1.F5 (GND), U1.F6 (GND), U1.F7 (GND), U1.G5 (GND), U1.G6 (GND), U1.G7 (GND), U1.H5 (GND), U2.3 (GND), U3.C1 (VSS), U3.E5 (VSS1), U4.D1 (VSS1), U4.E6 (VSS2), U5.2 (GND), U6.2 (GND), U7.2 (GND), VGA1.0 (PAD), VGA1.5, VGA1.6, VGA1.7, VGA1.8, VGA1.10, Y1.2 (CASE_GND)
unnamed: C12.1, C14.1, R11.2, U1.J6 (VCCPLL0)
unnamed: C12.2, C14.2, U1.L6 (GNDPLL0)
unnamed: C13.1, C15.1, R12.2, U1.C6 (VCCPLL1)
unnamed: C13.2, C15.2, U1.C5 (GNDPLL1)
unnamed: C32.2, R27.2, R28.1, U6.6 (FB)
unnamed: C33.2, R29.2, R30.1, U7.6 (FB)
unnamed: D2.1 (K), R20.2
unnamed: FB1.2, J2.A4 (VBUS), J2.A9 (VBUS), J2.B4 (VBUS), J2.B9 (VBUS)
unnamed: J2.A5 (CC1), R5.1
unnamed: J2.B5 (CC2), R10.1
unnamed: L1.1, U6.3 (SW)
unnamed: L2.1, U7.3 (SW)
unnamed: R14.2, U2.1 (DATA)
unnamed: R15.2, U2.5 (CLK)

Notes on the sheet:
0.6V * (1 + (120/120)) = 1.2V
0.6V * (1 + (210/47)) = 3.28V
Note: CSPI_SS has 10K pull-up on MMOD module.
Riegel Computer

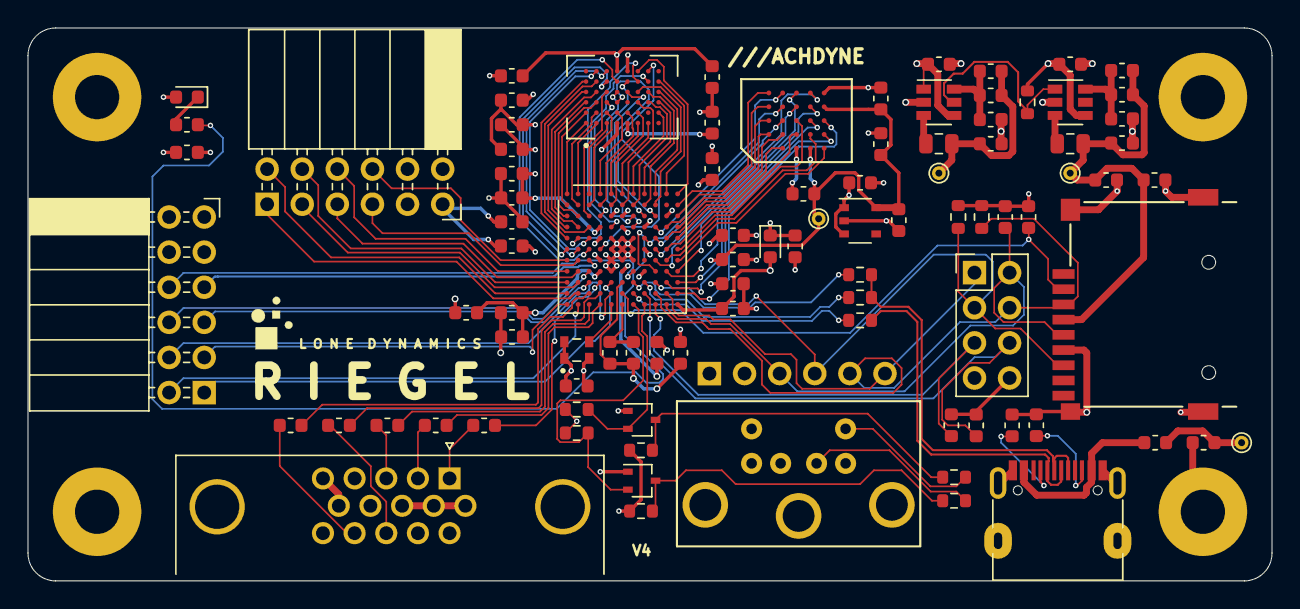
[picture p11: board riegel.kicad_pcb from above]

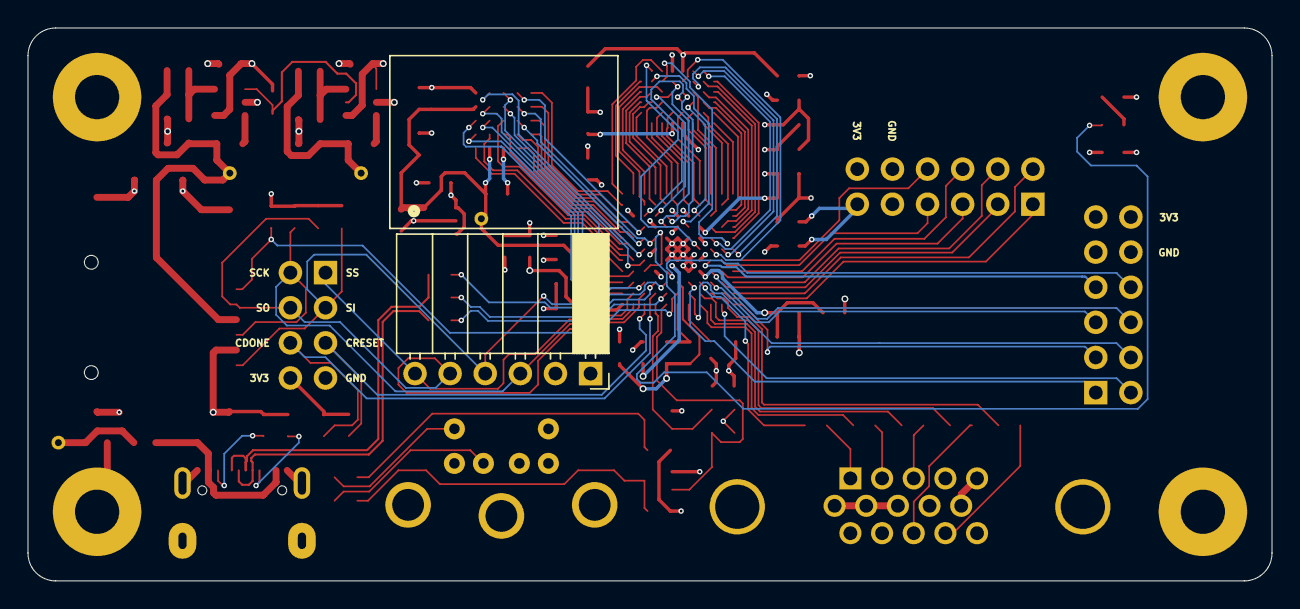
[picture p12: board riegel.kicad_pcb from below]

Board: 4 copper layers, 90.0 x 40.0 mm, 98 parts (2 on the bottom side), 124 nets.

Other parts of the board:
CONFIG-MMOD: LD-MMOD

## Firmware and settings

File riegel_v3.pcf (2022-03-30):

set_io CLK_48	L5

set_io LED_A	H9

# PMOD_A
set_io PMOD_A1  J5
set_io PMOD_A2  L1
set_io PMOD_A3  J3
set_io PMOD_A4  G3
set_io PMOD_A7  L2
set_io PMOD_A8  K5
set_io PMOD_A9  H3
set_io PMOD_A10 H7

# PMOD_B
set_io PMOD_B1  K2
set_io PMOD_B2  J2
set_io PMOD_B3  H2
set_io PMOD_B4  G2
set_io PMOD_B7  K1
set_io PMOD_B8  J1
set_io PMOD_B9  H1
set_io PMOD_B10 G1

#set_io UART_CTS  K2
#set_io UART_RX   J2
#set_io UART_TX   H2
#set_io UART_RTS  G2

# --

# VGA
set_io VGA_R   J4
set_io VGA_G   L4
set_io VGA_B   L3
set_io VGA_HS  K4
set_io VGA_VS  K3

# PS/2
set_io PS2_DAT	L7
set_io PS2_CLK	L8

# USB
set_io USB_DP J8
set_io USB_DP_PU J7
set_io USB_DN K7

# MMOD/SD SPI BUS
set_io SPI_SS_FLASH  K10
set_io SPI_SS_SD		K6
set_io SPI_SCK       L10
set_io SPI_MISO      J9
set_io SPI_MOSI      K9
set_io SD_CS 			K6

# STATIC RAM
set_io SRAM_A0		C1
set_io SRAM_A1		D1
set_io SRAM_A2		E1
set_io SRAM_A3		C2
set_io SRAM_A4		D2
set_io SRAM_A5		C4
set_io SRAM_A6		C3
set_io SRAM_A7		C7
set_io SRAM_A8		A7
set_io SRAM_A9		A8
set_io SRAM_A10	A9
set_io SRAM_A11	A10
set_io SRAM_A12	B7
set_io SRAM_A13	B8
set_io SRAM_A14	B6
set_io SRAM_A15	B9
set_io SRAM_A16	C8
set_io SRAM_A17	C9

set_io SRAM_D0		E3
set_io SRAM_D1		F1
set_io SRAM_D2		F2
set_io SRAM_D3		F3
set_io SRAM_D4		D7
set_io SRAM_D5		E2
set_io SRAM_D6		A11
set_io SRAM_D7		F4
set_io SRAM_D8		A2
set_io SRAM_D9		A3
set_io SRAM_D10	B3
set_io SRAM_D11	A4
set_io SRAM_D12	B4
set_io SRAM_D13	B5
set_io SRAM_D14	A5
set_io SRAM_D15	A6

set_io SRAM_CE		D3
set_io SRAM_WE		D5
set_io SRAM_OE		B1
set_io SRAM_LB		A1
set_io SRAM_UB		B2

# OPI PSRAM
set_io HRAM_ADQ0	J11
set_io HRAM_ADQ1	G10
set_io HRAM_ADQ2	G9
set_io HRAM_ADQ3	H10
set_io HRAM_ADQ4	F9
set_io HRAM_ADQ5	K11
set_io HRAM_ADQ6	J10
set_io HRAM_ADQ7	G11
set_io HRAM_DQ8	F10
set_io HRAM_DQ9	E11
set_io HRAM_DQ10	D11
set_io HRAM_DQ11	C11
set_io HRAM_DQ12	B11
set_io HRAM_DQ13	E8
set_io HRAM_DQ14	D9
set_io HRAM_DQ15	H11
set_io HRAM_DQS0	F11
set_io HRAM_DQS1	E9
set_io HRAM_CK		E10
set_io HRAM_CE		D10

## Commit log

2022-03-14 add v1 schematics
2022-03-18 add v3 schematics
2022-03-18 update v3 schematics
2022-04-30 add riegel case
    [riegel.scad]
2023-04-20 add pcb
    [riegel.kicad_pcb, riegel.kicad_sch]
2023-06-30 improve corner radius
    [riegel.scad]
